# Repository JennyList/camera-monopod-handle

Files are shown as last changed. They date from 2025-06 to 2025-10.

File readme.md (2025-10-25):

# A monopod handle for your camera

Jenny List 2025
CC-BY-SA 4.0

## About

This is a 3D printed handle for a camera, with a tripod screw at the top and a pointed metal end for greater robustness than a 3D print when resting on a hard surface. I found I needed something a little more than just my mini tripod in the closed position.
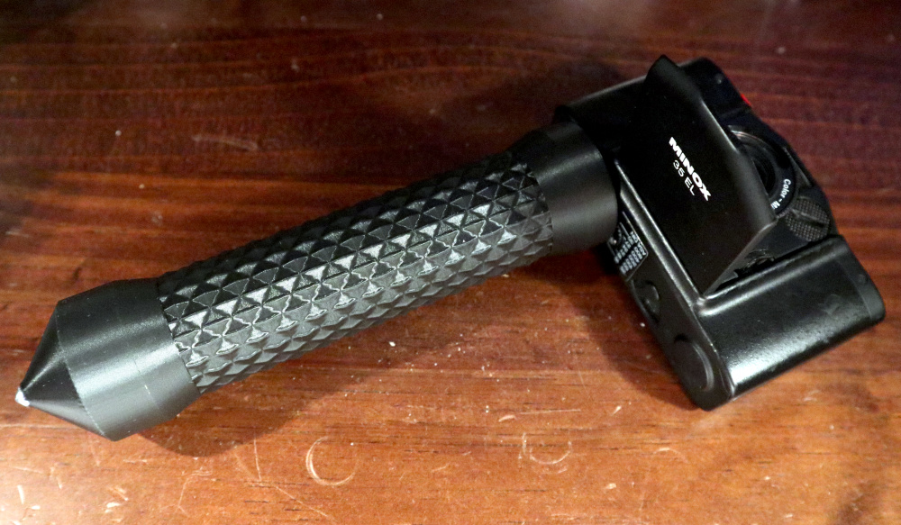
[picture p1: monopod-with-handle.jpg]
The handle on a desk, with a Minox 35mm camera attached to it.


## You Will Need:

1. A print of camera-monopod-handle.stl. I printed mine on a Prusa Mini, with a brim, and 40% infil for a little bit of robustness in the field.
2. A 1/4" 20 bolt. Mine are about 50mm or 2" long, with a thread 20mm or 4/5" long.

## To Assemble:

Cut the bolt as shown, with a hacksaw. Discard the hexagonal head, and file off any burrs.
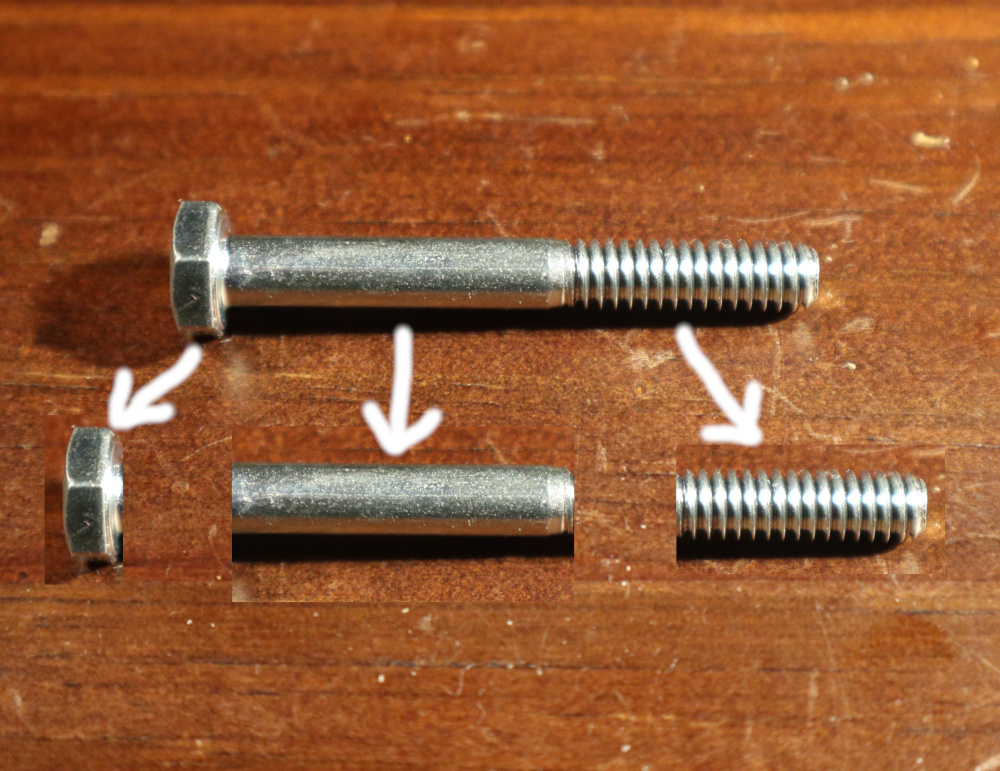
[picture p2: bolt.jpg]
A bolt, with cut marks.

The threaded part of the bolt should screw into the hole at the top of your print. It's designed such that with a 20mm thread, the required 5mm protrudes to attach to the camera.
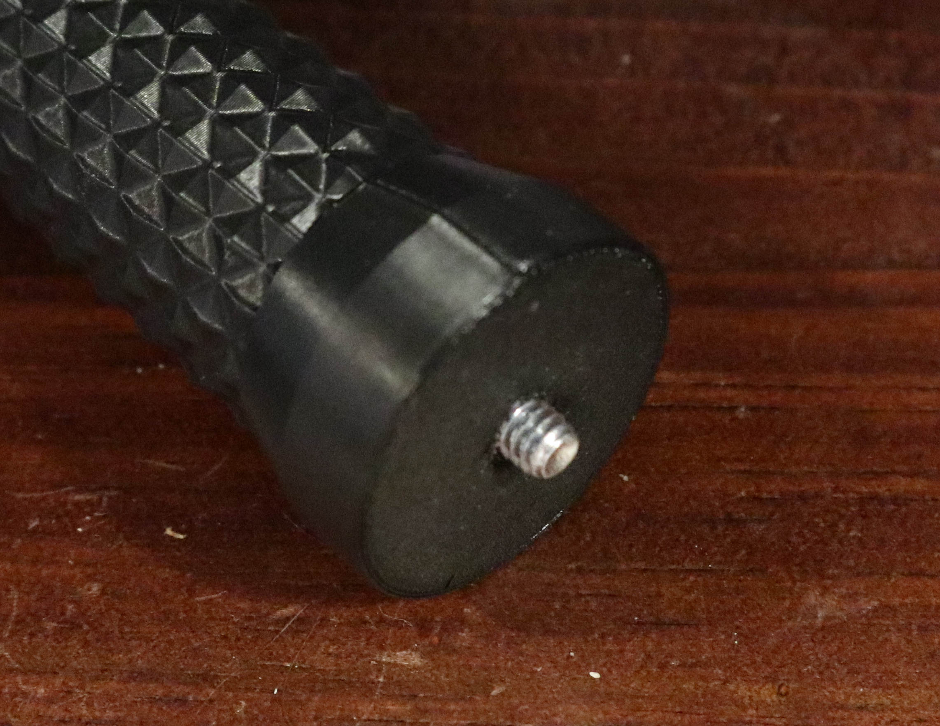
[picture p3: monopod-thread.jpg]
The thread, in the top of the handle.

Meanwhile the straight piece of the bolt should be an interference fit at the pointed end of the stick. I knocked mine in with some light blows from a small hammer, use a press here if you have one. Then you can grind it to a point. I did this with a bench grinder. The result is bare steel so could corrode, I don't intend to get it wet but I may apply some paint.
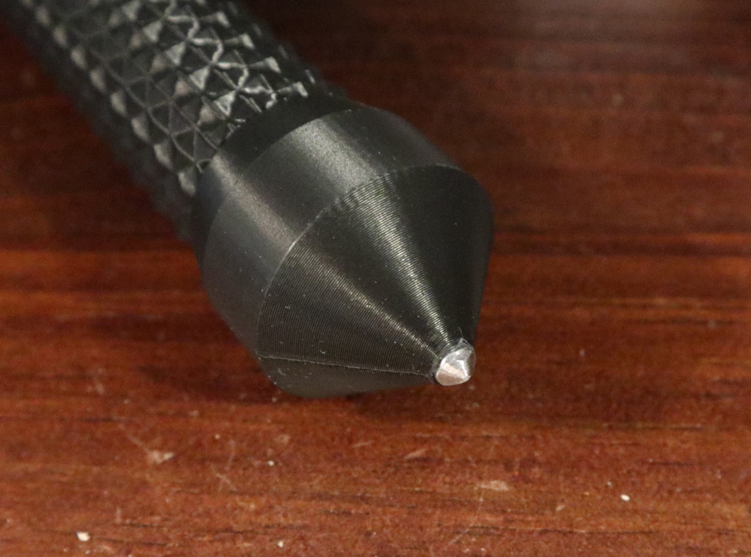
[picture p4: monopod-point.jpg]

I did not use any glue, but if you find your thread or point is loose, you can.

## In Use:

I've now used this with everything from small 35mm cameras through mirrorless digital and DSLR cameras, to 8mm moive cameras. It suits my video style, but if there's an addition I may make in the future its a provision for a Bluetooth trigger.

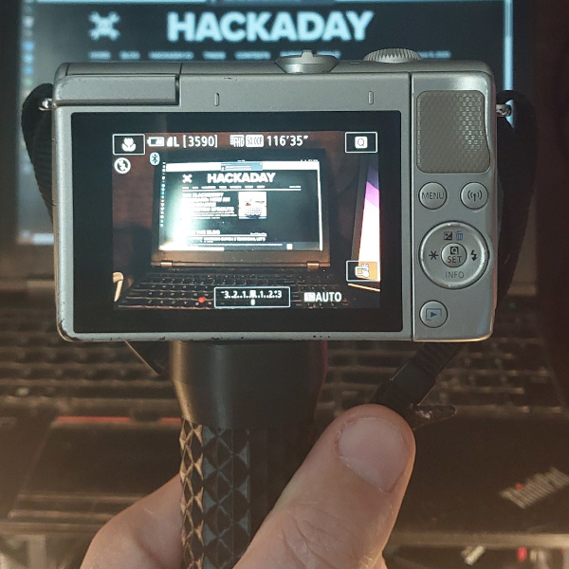
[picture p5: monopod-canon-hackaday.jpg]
The handle in use with a Canon mirroless camera, photographing the Hackaday website on a laptop screen.


## Licence

This model is licensed under the [Creative Commons Attribution Share Alike 4.0 International licence](license.md).

It uses Stephen Kent's [Knurled Surface Library for OpenSCAD](https://github.com/smkent/knurled-openscad), which is licensed under the Creative Commons CC0 1.0 Universal (Public Domain) License.



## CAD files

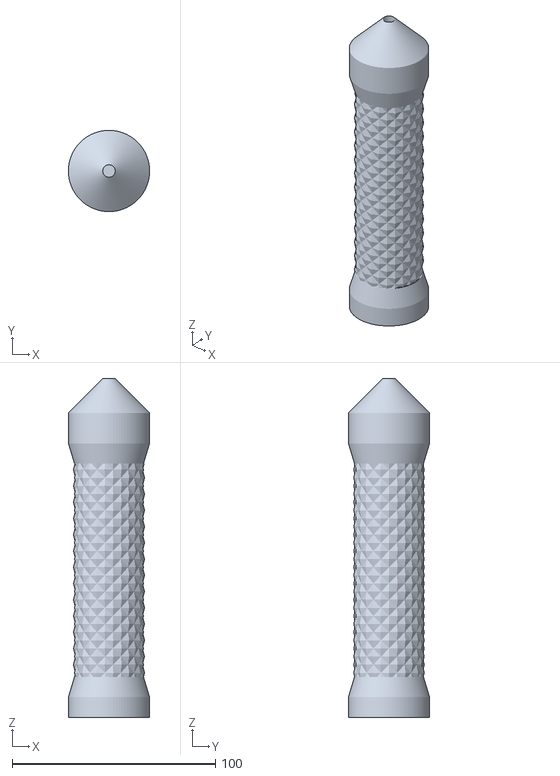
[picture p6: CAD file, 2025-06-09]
camera-monopod-handle.stl
40.0 x 40.0 x 166.9

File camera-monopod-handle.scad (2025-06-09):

/*

A monopod handle for your camera
Jenny List 2025
CC-BY-SA 4.0

*/

$fn=90;

//
// This makes use of Stephen Kent's knurled.scad library.
// It can be found at https://github.com/smkent/knurled-openscad.
// It's licensed under the Creative Commons CC0 1.0 Universal (Public Domain) License.
//
use <./knurled.scad>

module handle(){
    translate ([0,0,150]) cylinder(20,20,0); //Single point rest
    translate([0,0,135]) cylinder(15,20,20); //cylinder
    translate([0,0,125]) cylinder(10,17,20); //top of hand grip
    translate ([0,0,15]) knurled_cylinder(110,34,8,8,1,0,0); //knurled part of hand grip
    translate ([0,0,10]) cylinder(10,20,17); //bottom of hand grip
    cylinder(10,20,20); //platform for camera
}

difference(){
    handle();
    cylinder(15,3.1,3.1); //space for tripod screw
    translate([0,0,15]) cylinder(5,3.1,0); //cone on top of tripod screw for printing without supports
    translate([0,0,155]) cylinder(30,3.1,3.1); //space for end point
}

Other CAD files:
knurled.scad
